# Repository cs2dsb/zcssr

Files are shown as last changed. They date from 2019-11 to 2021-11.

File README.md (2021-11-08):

# ZCSSR - Zero crossing solid state relay controller

A PCB and software for a SSR controller that monitors mains AC zero crossings to determine when to turn the SSR on.

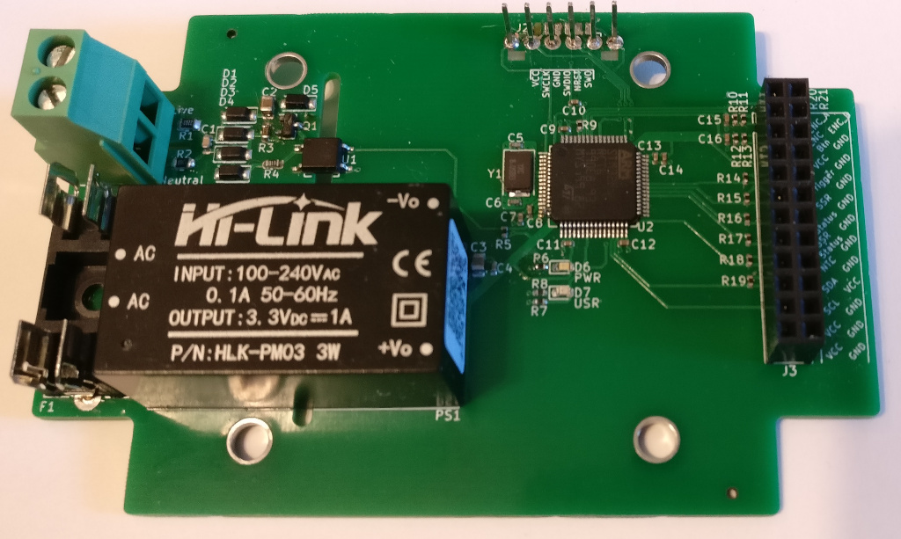
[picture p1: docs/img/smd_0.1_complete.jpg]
Image of v0.1 fully assembled

[more images](docs/img)

## Why

I wanted to build a spot welder from an old MOT (microwave oven transformer) but wasn't satisfied with simply enabling the SSR at random because this makes the pulse +/- 1 half mains cycle (10ms on 50Hz, 8.3ms on 60Hz). It probably doesn't make much difference in the grand scheme of things but I wanted to know exactly how long the pulses were. 

This controller solves that issue by monitoring the mains zero crossing and triggering the SSR just before a zero crossing - the SSR has it's own zero crossing circuit to actually turn on it's output so as long as the controller doesn't fire more than 1 cycle early it will work as expected.

I also wanted to completely finish an embedded project written in rust and this project seemed about the right size undertaking.

## Uses

* Spot welder
* Reflow oven
* Sous vide
* Smoker
* Probably other things that need temp input (K-Type thermocouple) and switched mains ouput

## Features

* Zero crossing detection circuit
  * Pulse at least 0.4ms before the zero crossing
  * Isolated
  * 100-240V, 50/60Hz
  * [Details](docs/SimpleIsolatedZeroCrossDetector.pdf)
* UI
  * Quadrature encoder with push button 
  * LED for general status
  * LED for SSR status
  * 4 digit 14-segment LCD display. I2C
  * Trigger input 
* Temperature monitoring
  * NTC thermister for monitoring SSR/Transformer temperature
  * K-Type thermocouple input. MAX31855
* STM32F1 64-pin LQFP MCU. Specifically STM32F103RCT but any should work
* SWD (serial wire debug) programming & debugging
* USB hardware. In theory USB programming will be possible but not yet implemented

## Tools used

Not a complete list. Will add to it as features get implemented

* [Kicad](http://www.kicad.org/)
* [Rust](http://www.rust-lang.org/)
  * [cortex-m](http://github.com/rust-embedded/cortex-m) and [cortex-m-rt](http://github.com/rust-embedded/cortex-m-rt)
  * [cortex-m-rtfm RTOS](http://github.com/rtfm-rs/cortex-m-rtfm)
  * [stm32-rs peripheral register definitions](http://github.com/stm32-rs/stm32-rs)
  * [stm32f1xx-hal HAL implementation](http://github.com/stm32-rs/stm32f1xx-hal)
  * [adafruit-alphanum4.rs driver for Adafruit 14-segment LED Alphanumeric Backpack](http://github.com/cs2dsb/adafruit-alphanum4.rs)
    * [ht16k33 LED driver](http://github.com/jasonpeacock/ht16k33)

## Documentation

### Getting started

* Clone the repo
* Run `./bootstrap` script which will:
  * Initialize git submodules
  * Run `firmware/bootstrap` which will:
    * Checks if OS dependencies are installed
      * Currently `gcc`, `gdb`, `openocd` and `libudev-dev`
      * `sudo firmware/install_apt_deps` will install these deps if you are using a distribution that uses `apt`
    * Install or update rustup
    * Install required rust embedded toolchains
    * Install utils from crates.io
      * cargo-binutils
      * cargo-watch
      * llvm-tools-preview
      * serialitm
    * Run a cargo check, build and doc of the firmware (will take quite a while the first time)
* Direct flashing the the device
  * `firmware/deploy_standalone` will start openocd, flash the program and restart the device
* Debugging with gdb
  * `firmware/run_openocd` in one terminal
  * `firmware/release` or `firmware/debug` to build and launch gdb
  * Take a look at `firmware/openocd.gdb` and the scripts above to tweak the behaviour
* Log output
  * Firmware built with `--feature itm` will log over SWD
  * `firmware/monitor_itm` will launch `serialitm` to print this output with the ITM control characters stripped out. You may need to tweak the script if your uart dongle isn't `/dev/ttyUSB0`
* Tmux
  * `firmware/tmux_workspace` is a script that will open a tmux session with `firmware/run_openocd`, `firmware/monitor_itm` and `firmware/watch` in differnt panes to make development easy. Just type `./release` in one of the spare panes to deploy the software with gdb

### ITM logging

The code uses ITM logging to indicate start up progress and log info like temperatures and user config. If the ITM feature is enabled, the microcontroller won't run without openocd connected because there is some debug config openocd does to the chip that makes ITM work. I've added the obvious checks to the [itm_logger](https://github.com/cs2dsb/itm_logger.rs) crate but there's still something missing that I haven't got to the bottom of yet. There's [an issue](https://github.com/cs2dsb/itm_logger.rs/issues/1) to track it. The bottom line is if you want to be able to plug the hardware into the mains without OpenOCD connected you need to disable the `itm` feature (`firmware/deploy_standalone` already does this.)

### More info

Check [the docs folder](docs) for information on setting up the dev environment and various info on making the hardware.

## Mains warning

* Mains is dangerous, see the disclaimer
* A specific issue you might hit is powering the device over USB during development then plugging the mains in while the USB dongle is still attached. The mains will power the AC/DC on the board and that will backfeed 5v into the 3.3v/5v provided by the dongle. It's fine to leave the dongle connected if you disconnect it's 3.3v/5v line - only ground, swd, swclk should be connected to the ST-LINK if you want to plug the mains in. The UART connected to ground and swo is also fine. If you do backfeed 5v to the ST-LINK expect the ST-LINK to break as a minimum and the USB port it's connected to as a worst case. 

## Disclaimer

* This project uses mains electricity and will kill you if you handle it improperly
* You are responsible for your own safety
* Despite best efforts the author makes no guarantees that this design is safe, fit for purpose or meets any quality standards
* If you decide to build this or a similar device you must understand and take necessary safety precautions before proceeding
* The author cannot be held responsible for any damages or any form of loss that comes as a result of using any information found in this project

## License

This template is licensed under either of

- Apache License, Version 2.0 ([LICENSE-APACHE](LICENSE-APACHE) or
  http://www.apache.org/licenses/LICENSE-2.0)

- MIT license ([LICENSE-MIT](LICENSE-MIT) or http://opensource.org/licenses/MIT)

at your option.

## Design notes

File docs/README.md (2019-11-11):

# Docs

## Technical

[Setting up the dev environment](setting_up_dev_env.md)

[Generating gerbers and fab outputs](generating_gerbers_and_fab_outputs.md)

[Placing an order for assembled boards with JLCPCB](placing_jlcpcb_order.md)

## Flavour

[Project log](project_log.md)

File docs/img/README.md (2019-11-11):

# TH_v0.1

* ATMEGA328P based

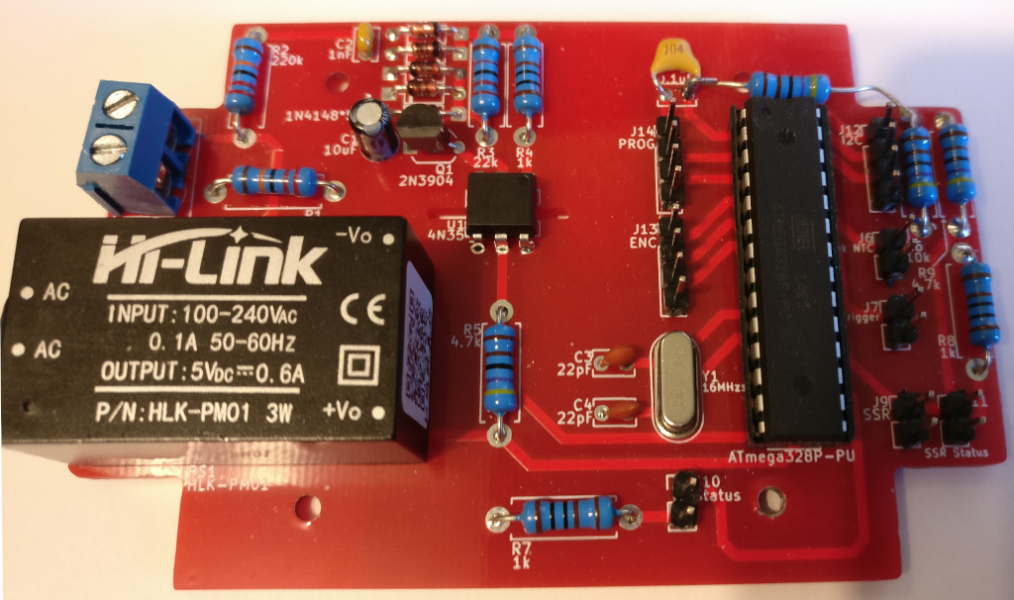
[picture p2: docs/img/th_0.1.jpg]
Image of TH v0.1 fully assembled


# SMD_v0.1

* STM32F1 based 

### Board as it came from JLCPCB assembly service

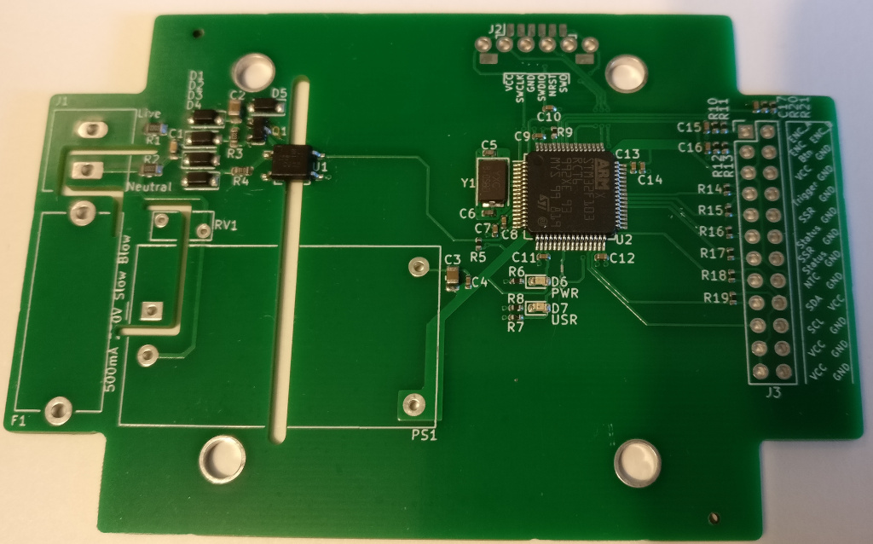
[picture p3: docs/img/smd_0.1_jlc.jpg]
Image of v0.1 from jlc


### Fully assembled with through hole components

Image of v0.1 fully assembled

# SMD_v0.2

* Added MAX31855
* Added USB 
* Moved connectors closer to edges to free up space in the middle of the enclosure

### Render from kicad
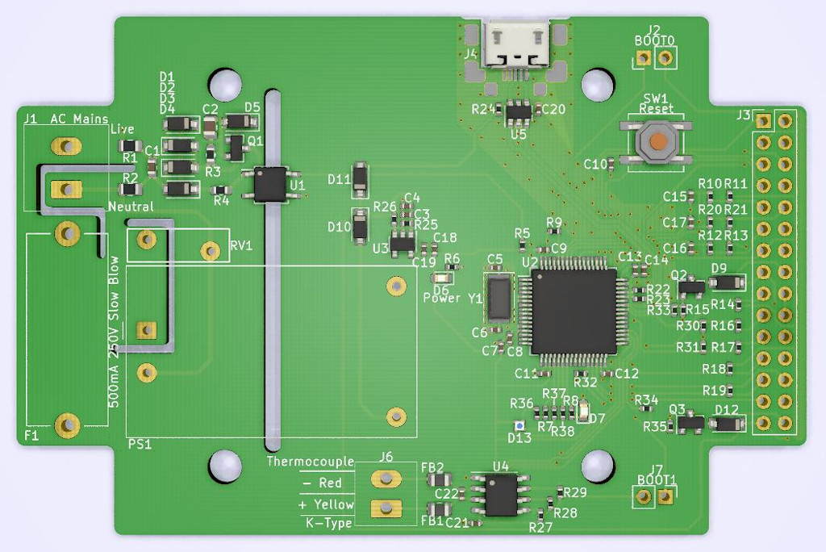
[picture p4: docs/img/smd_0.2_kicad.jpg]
Image of v0.2 kicad render


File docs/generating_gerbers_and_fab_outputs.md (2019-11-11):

# Generating gerbers and fab outputs

## Bill of materials
1. Open the schematic 
2. Click the BOM button: BOM button
3. Select `bom2grouped_csv`
4. Press `Generate`
5. Navigate to the project folder in the terminal
6. Move "zero_crossing_detector" (note no extension) to "print/zero_crossing_detector-bom.csv"
    * `mv zero_crossing_detector print/zero_crossing_detector-bom.csv`
7. Close the schematic

## Gerbers
1. Open the kicad_pcb
2. Press `b` to refill zones
3. Click the Plot button: Plot button
4. Check the options are correct
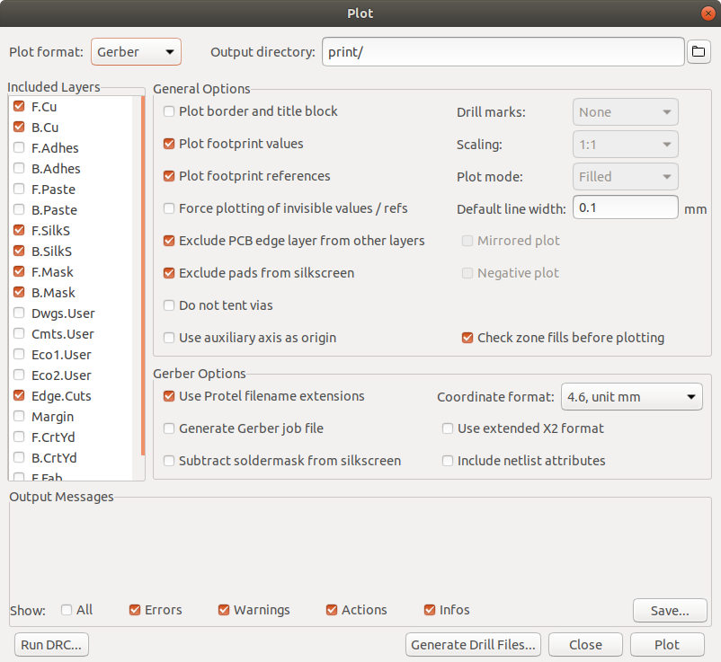
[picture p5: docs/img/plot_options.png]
Plot options
    
5. Press `Plot`
6. Press `Generate Drill Files...`
7. Check the drill options are correct
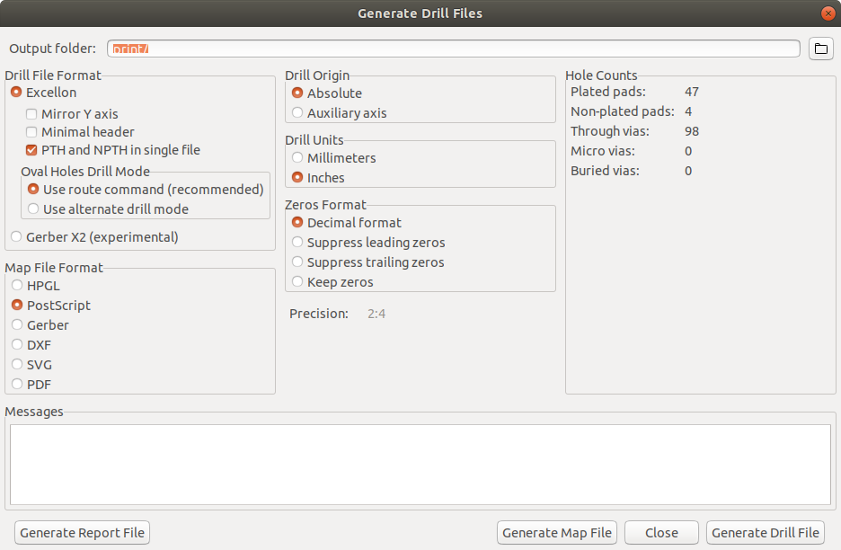
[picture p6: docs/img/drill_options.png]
Drill options
    
8. Press `Generate Drill File`
9. Close the drill window
10. Close the plot window

## Footprint position file
1. Still in kicad_pcb
2. Click File | Fabrication Outputs | Footprint Position (.pos) File...
3. Check the pos options are correct
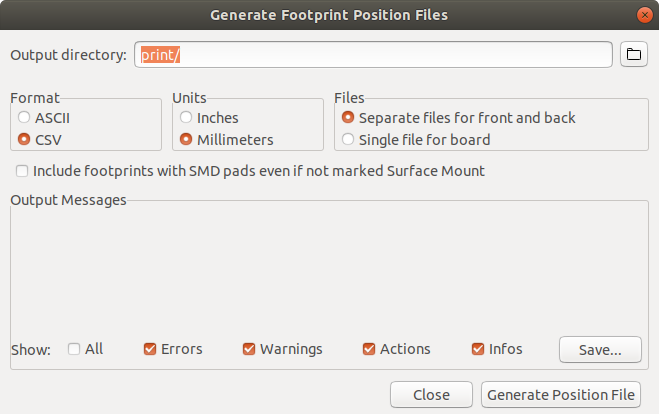
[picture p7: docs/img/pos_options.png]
Footprint pos options
    
4. Press `Generate Position File`

## Post processing the files
1. Go to the project folder in the terminal
2. Go to the print folder
3. Run `rename_gbrs.sh` which will
    * Delete any old `print.zip`
    * Rename the `PosX` and `PosY` columns in the footprint pos file to `Mid X` and `Mid Y` as required by JLCPCB
    * Make sure the BOM is csv rather than semi-colon separated (probably no longer necessary)
    * Rotate `Q1` to fix alignment on reel
    * Zip everything up in `print.zip`

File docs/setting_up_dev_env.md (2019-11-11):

# Setting up the dev environment

This project has been developed on a Linux development environment. The scripts and steps discussed below are unlikely to work on Windows or OSX. [The Embedded Rust Book](https://rust-embedded.github.io/book/) introduction section has a detailed installation guide for all platforms. You will also need to adjust `firmware/.cargo/config` which discussed [in the hardware section of the book](https://rust-embedded.github.io/book/start/hardware.html). The [cortex-m-quickstart repo](https://github.com/rust-embedded/cortex-m-quickstart) also has lots of useful information. If you follow that then skip to the [Project specific section](#project-specific) you should be all set up.

## Tools
### openocd
* Install [openocd](http://openocd.org/getting-openocd/)
* `apt install openocd` will likely be sufficient if you are using Ubuntu or Debian
* If you have any issues (particularly around the device not being reset correctly) consider installing a more up to date version from source

### rustup
* Install [rustup](https://rustup.rs/)

### bootstrap `(firmware/bootsrap)`
This script will 
* add the required toolchains using `rustup`
* add `cargo-binutils`
* add `llvm-tools-preview`
* add `cargo-watch`
* kick off a full build & doc 

## Project specific
### run_openocd `(firmware/run_openocd)`
This script will 
* launch `openocd` with the included `openocd.cfg` configuration

You'll need to have this running for [release](#release-firmwarerelease), [debug](#debug-firmwaredebug), [device_reset_halt](#device_reset_halt-firmwaredevice_reset_halt) and [device_reset_run](#device_reset_run-firmwaredevice_reset_run) to work correctly.

### watch `(firmware/watch)`
This script will
* monitor the rust source and build whenever a file changes

### release `(firmware/release)`
This script will
* run `device_reset_halt` to ask openocd to reset and halt the target hardware
* run the release version of the `main` binary (`src/bin/main.rs`) on the target hardware using `gdb`

### debug `(firmware/debug)`
As [release](#release-firmwarerelease) but in compiled in release mode which makes stepping through code easier but can be extremely slow in some circumstances. Suggest adding `cortex_m::asm::bkpt()` just before whatever you want to step through then running `debug`.

### device_reset_halt `(firmware/device_reset_halt)`
This script will
* telnet to openocd (127.0.0.1:4444) and issue a `reset halt` command which will cause the MCU to reset and stop ready to be programmed

### device_reset_run `(firmware/device_reset_run)`
This script will
* telnet to openocd (127.0.0.1:4444) and issue a `reset run` command which will cause the MCU to reset and run whatever is currently on it's Flash/SRAM (depending on BOOT0/1 jumper config)

### tmux_workspace `(firmware/tmux_workspace)`
This script will
* start or resume a `tmux` session
* split the window into 5
* run `watch`
* run `../../itm_log` //TODO: upload this tool
* run `openocd`

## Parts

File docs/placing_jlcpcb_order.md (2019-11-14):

# Placing an order for assembled boards with JLCPCB

Make sure you've run through [Generating gerbers and fab outputs](generating_gerbers_and_fab_outputs.md) first.

1. Head over to [JLCPCB](https://jlcpcb.com/quote) and log in/register
2. Press `Add your gerber file`
    
    Add gerber button
3. Upload `print/print.zip` 
4. Check the options to make sure they are compatible with SMT assembly:
    * Layers: 2
    * PCB Thickness: 1.6
    * PCB Color: Green
    * Copper Weight: 1oz
    * Panel By JLCPCB: No
    * Gold Fingers: No
    * Castellated Holes: No
    * Different Design: No
    * **Specify Order Number: Yes**
5. Enable `Assemble your PCB boards`

    Assemble your PCB boards
6. Select the top side for assembly
7. Press `Confirm`
8. Press `Add BOM file`
    
    Add bom file
9. Upload `print/zero_crossing_detector-bom.csv`
10. Press `Add CPL file`
    
    Add cpl file
11. Upload `print/zero_crossing_detector-top-pos.csv`
12. Press `Next`
13. Check and confirm every part against the BOM
    * It's pretty good at matching most but occasionally you'll have to pick manually
    * There are currently no connectors in the parts database so the USB and other connectors will have to be ordered separately and manually installed
14. Press `Next`
15. Check the Pin 1 markers (red dots) in the `Review Parts Placement` preview
16. Press `Save to cart`
17. Checkout

## LCSC Parts
There are some parts that JLCPCB can't assemble which can be ordered on LCSC.

If you registered with LCSC before 12-Mar-2019 you can get a discount/free shipping on LCSC parts when you have a JCPCB order waiting production. [See for details](https://support.lcsc.com/article/24-do-you-offer-combine-shipment-with-pcbs)

These parts need to be ordered (check BOM in case this list gets missed from an update):
* C52028 - MAX31855
* C89120 - Phoenix Contact 1711725 (Mains input)
* C89122 - Phoenix Contact 1751248 (Thermocouple input)
* C206887 - Littlefuse fuse holder
* C187509 - Littlefuse fuse cover
* C56496 - Header pins
* C136145 - NTC thermistor
* C140500 - 500mA slow blow fuse
* C209903 - 5V AC-DC power module
* C233184 - Varistor
* C361165 - ALPS rotary encoder (This one is detentless and doesn't have a threaded mounting column. There are a dozen different styles if you search for ALPS "coded rotary switches". Most of EC11 range is suitable but check for "With" in "Push-on switch" column in datasheet. EC12D have push buttons and are all suitable but are only available with detents and in relatively low pulse/rev)

## Other Parts
* [Enclosure](https://www.banggood.com/100x68x50mm-IP65-Waterproof-Electronic-Project-Enclosure-Case-DIY-Enclosure-Instrument-Case-p-1260023.html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) - the pcb is designed to fit in this box and there's **probably** enough space to fit the display, rotary encoder, LEDs and maybe even the SSR inside too. Check the [docs folder](..) for assembly details once the next version of the hardware has been tested
* [Display](https://www.banggood.com/5pcs-4-bit-Pozidriv-0_54-Inch-14-segment-LED-Digital-Tube-Module-Green-I2C-Control-2-line-Control-LED-Display-Screen-Module-p-1565722.html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) - the firmware expects this display but you could modify it to accept any I2C display
* [STLink](https://www.banggood.com/3pcs-3_35V-XTW-ST-LINK-V2-STM8STM32-Simulator-Programmer-Downloader-Debugger-With-20cm-Dupont-Wire-p-1183115.html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) - for programming the board. Listing is for 3; it's probably a good idea to get spares in case you blow one up (I did)
* SSR - I bought several `Crouzet 25A` and tore one down to make sure it was genuine. The Fotek SSR-25 relays are common and widely used but they are also almost all clones of varying quality. Some clones have 16A triacs inside which would still be perfectly sufficient but others have 4-8A triacs which is probably a fire waiting to happen if you're building a welder. You can get Crydom and other genuine SSRs on farnell/mouser/digikey/etc but expect to pay 5x as much as the clones. **If you do go with an SSR of unknown quality never leave it plugged in to the mains unattended and be prepared in case of fire**. Regardless of which SSR you go for make sure the NTC thermistor is connected to it's heatsink during operation. Some videos about clone SSRs and failures: [melted down](https://youtu.be/FV9t1GFVbhU), [clone teardown](https://youtu.be/DxEhxjvifyY).

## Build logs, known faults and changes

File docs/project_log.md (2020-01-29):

# Project log

## 5-Sept-2019

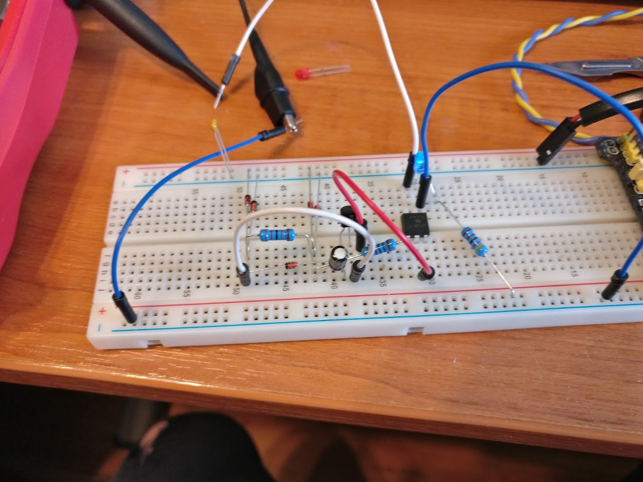
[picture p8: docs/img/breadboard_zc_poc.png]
breadboard poc
* Breadboard prototyped zero crossing circuit based on [this circuit](SimpleIsolatedZeroCrossDetector.pdf) (originally from drextel.net but the domain has sadly gone dormant). 
* There are simpler ZC circuits but this one appears to have some additional benefits, works really well and doesn't add much to the BOM cost
* Arduino POC code using hardware timer to detect ZC edges and ISR to record the timer count
    * Works ok, measures the width and time of the pulse with good precision
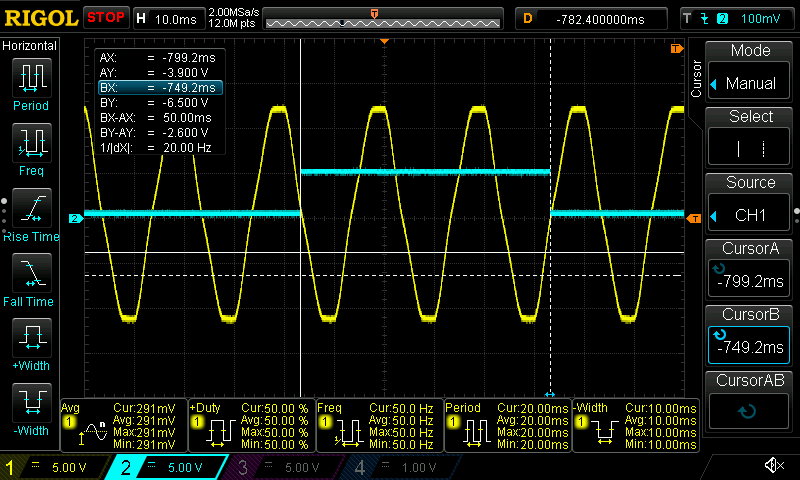
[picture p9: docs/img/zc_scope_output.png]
gpio output against AC
    * GPIO output on scope looks good against AC waveform 

## 6-Sept-2019

* Received Couzet SSRs
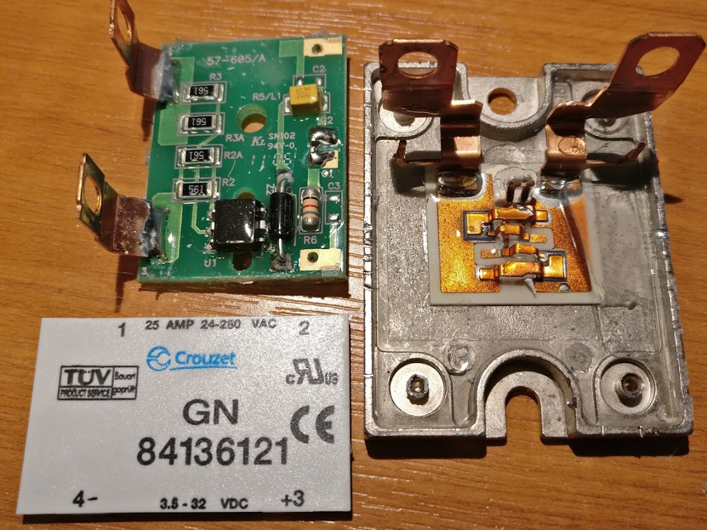
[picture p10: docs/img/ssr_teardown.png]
ssr teardown
* Tore one down to make sure they are genuine 
* Hooked up SSR output to scope and showed that triggering GPIO in ISR was sufficiently before the ZC to correctly enable the SSR in time for the ZC

## 8-Sept-2019

* Ordered TH_v0.1 boards from JLCPCB

## 25-Sept-2019

* Received TH_v0.1 boards Image of TH v0.1 fully assembled
* Missing pullup on RST. Working as expected other than that
* 14-Segment Adafruit display working nicely over I2C
* Rotary encoder seems like a reasonable input device for the kind of config this needs (pulse1, delay1, pulse2, delay2)
* NTC working

## 7-Oct-2019

* Ordered SMD_v0.1 boards assembled from JLCPCB
* STM32F1 available for assembly as a basic part
* STM32 has richer set of peripherals than ATMEGA328P
    * Timer can do quadrature encoder input with no software interaction
    * Timer can do PWM input capture to measure the frequency and duty of the ZC signal
    * Timer can be configured in one-shot mode to enable the SSR for a given time and have the hardware turn it off regardless of a crashed program or delayed ISR or something
* STM32 can also be programmed with rust and the F1 has pretty good support

## 22-Oct-2019

* Received SMD_v0.1 boards from JLCPCB Image of v0.1 from jlc
* Identified issues:
    * Q1 Base and Collector are switched. Resolved with some solder bodging
    * Varistor/Mov leads are too thick for holes. Resolved with some solder bodging
    * Pwr led is annoyingly bright with 150Ω resistor. Had a 680Ω to replace it with but still too bright. Changed to 1k in schematic
    * ZC input on TIM2_CH3 can't be used for PWM input. Fortunately CH1 & CH2 are adjacent so resolved with some solder bodging

## 28-Oct-2019

* Note to self: don't plug the mains in when loose dupont wires are nearby. Destroyed ST-Link and F1 on POC board
* Ordered fuse cover to partially protect mains contacts
* Added longish ribbon with all low voltage outputs and fitted lid of box so nothing can get in by accident

## 3-Nov-2019

* Recieved replacement ST-Link
* Basically all the bits are implemented in rust. Few PRs for stm32f1xx-hal to enable extra timers
* Implemented driver for 14-segment display [adafruit-alphanum4.rs](https://github.com/cs2dsb/adafruit-alphanum4.rs)
    * Added to rust-embedded awesome list which is nice. Hopefully it'll be useful to someone

## 11-Nov-2019

* Did quite a bit of documentation for the repo
* Finished updating SMD_v0.2 PCB ready to order
    * Added MAX31855K K-Type thermocouple interface IC to enable reflow oven use case
    * Added USB port, mainly as an experiment to see if I can get it working and useful (USB DFU mode would be amazing but failing that, something similar to the TS-100 USB functionality would be ok)
    * Added a physical reset button. In theory, SWD doesn't need hardware reset and openocd should be able to connect to the core with just CLK, DIO and GND but in practice I've had boards fairly regularly get into a state where it can't connect reliably. Resetting by shorting NRST to GND resolves this and the board will work without reset until the ST-Link is unplugged or the boards power is cycled. I haven't been able to get to the bottom of it - the core is running, the gpio for SWD hasn't been reconfigured and I've tried every permutation of reset_config in openocd. There's some speculation on some forums that the ST-Link firmware is to blame as it's not a proper JTAG adapter and merely emulates some features; I could buy a proper JTAG adapter to rule this out but I want these boards to be programmable by anyone with a cheap adapter. This programming faff partially fed into the desire to add USB and explore USB bootloading. 

## 13-Nov-2019

* Changed AC-DC module from 3.3V to 5V to allow 5V SSR (or relay) output
* Switched LDO to AP2112 as used on several Adafruit boards. It has better specs and doesn't require tantilum caps to be stable
* 5V in allows using simple diodes to block backfeeding AC-DC or USB 5V inputs
* Added transistors to control SSR and MISC outputs so they can be 5V rather than directly driven from MCU GPIO pins

## 15-Nov-2019

* Added tiny 1x1mm rgb LED to spare pins near the existing LED. Mainly want to see how bright this tiny LED is at ~5ma

## 16-Nov-2019

* Placed an order for the next version of the PCB

## 29-Nov-2019

* v0.2 PCBs arrived
* Updated the board pin hardware definitions
* Tested all the previously implemented features
    * It all still works
* RGB led added in this version is oriented incorrectly
* Haven't tested USB

## 9-Jan-2020

* Finished implementing [MAX31855](https://github.com/cs2dsb/max31855.rs) and testing thermocouple

## 14-Jan-2020

* Tested RTFM 5: issue I was previously seeing with hardware interrupts not getting called appears to be resolved
* Converted spot_welder to use RTFM 5 and some general housekeeping

## 19-Jan-2020

* Fitted the new hardware into the case and hooked up a transformer to test the ZC and mains side of things
* All working as expected - probably shouldn't be surprising but after taking a 2 month break I automatically assume all the hardware and code was rubbish and wouldn't work.

## 25-Jan-2020

* Brought all the tested bits a pieces together into basically finished spot welder
    * UI settings are snapshotted when the weld is triggered
    * Oscilloscope shows pulse lengths match configured values
* Refactored the UI out into zcssr lib
    * I originally thought it might be a useful reusable thing but actually a 4 digit display controlled with a rotary encoder is probably too specific to be much use elsewhere. Maybe it can be extracted later; some of the code like scrolling text might be useful...
    * As part of the refactoring I converted the display strings into GenericArray<AsciiChar, typenum::Uxx> and got rid of the current text buffer. This means there's no copying the strings when changing screens and each string is only as long as necessary not some MAX_LENGTH constant. I haven't worked out the memory savings but it feels better to have a zero cost, no copying version.
    * Experimented with using trait objects/dynamic dispatch to make the Ui/Screen api nicer but found that dynamic dispatch introduced a measurable (oscilloscope on toggled IO pin) delay of several hundred cycles. Since I'm matching on the current screen anyway static dispatch isn't much more of a hassle but does prevent something clean like self.with_current_screen(|screen| screen.do_the_thing()). To reduce duplicated match (self.current_screen) blocks I made a macro to plop the match around a closure - it basically mimics the api I would have done with trait objects except the closures are manually monomorphised by the macro.
* Trigger cable is picking up noise and causing the interrupt to run erroneously
    * Added hardware debouncing to the trigger input
    * Since a false interrupt on the trigger could cause a weld at an inopportune time I'll have to revisit it once the HW debouncing is in to see if I need to add a software solution on top - requiring a press longer than a given time and not occuring again within a given time would be fairly easy to implement and could provide more safety.
* Related to trigger noise, I'm also seeing erroneous data on the UART dongle I'm using when big mains devices turn on/off in the same room (electic heater, lights, printer). This happens when the mains plug for the ZCSSR isn't connected and everything is powered over USB so I don't really know what the exact cause is - the UART dongle has a high quality shielded cable, maybe it's noise being conducted to the USB ground? Who knows...

## 26-Jan-2020

* Moved majority of the hardware configuration out of spot_welder (the bin) into the crate board.rs
    * This should mean that creating new bins for reflow_oven, sous_vide, etc. will reuse most of this code and be fairly trivial - just the control algorithms for those specifc devices
    * The pattern I went for is the board has a trait `Configure` which it implements for the type aliases it defines for the hardware. The consumer then does `LedStatus::configure((gpiox.px1, etc))` to get a configured `LedStatus` back. The pattern of having an associated type on the trait that specifies the requred parameters was nicked from amethyst.rs's system trait. I'm not sure if this gives any benefit over a simple function configure_led_status(...)

## 27-Jan-2020

* Took the I2C hung fix I hacked into local copy of the hal out and put it in a separate crate: [i2c_hung_fix](https://github.com/cs2dsb/i2c_hung_fix.rs) since it only needs embedded-hal InputPin and Output pin and should work for anything that implements those on the I2C pins
* Moved the UI string to GenericArray code into a proc_macro so that the length of the array is correctly enforced. It still uses unsafe union transmuting but both sides lengths are calculated in the proc macro instead of manually entered so it should be safe enough. Once core::mem::transmute becomes a const_fn this will be unnecessary [see #53605](https://github.com/rust-lang/rust/issues/53605)

## 29-Jan-2020

* Shifted the PCB around to put the AC/DC supply is right on one of the short edges of the board in the hope this will fit more comfortably next to an SSR inside the enclosure
* Removed the RGB led, I only added it on a whim to test how bright and small the LED was. It's not much use inside the enclosure and it adds to the SMD assembly cost
* Switched from using hacky d2xx ITM log utility to [serialitm](https://crates.io/crates/serialitm) from crates.io which does everything needed for this project
    * If I add typed ITM data output for the reflow oven/sous vide to log temperatures I may need some extra features but this util is sufficient for now
* Updated bootstrap scripts and readme

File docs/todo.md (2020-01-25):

# Todo

## Firmware

### Shared
- Test basic hardware
    - [x] Debug LED on PCB near MCU
    - [x] Status LED to indicate ready, error, etc.
    - [x] Status LED to indicate SSR status. Typically same state as SSR_EN
    - [x] SSR output
        - [x] One shot timer to trigger fixed length pulse under hardware control
    - [x] Misc output (fans etc)
    - [x] Rotary encoder
    - [x] NTC thermister
    - [x] Zero crossing detection circuit
    - [x] Trigger
    - [x] I2C display
    - [ ] USB
    - [x] Thermocouple

## Hardware
- [x] Add hardware debouncing to trigger
- [x] Add pull-up to SCL
- [x] Make I2C pull ups optional since adafruit module already includes them
- [x] Make I2C pull ups 2.2k since 3.3v not 5v

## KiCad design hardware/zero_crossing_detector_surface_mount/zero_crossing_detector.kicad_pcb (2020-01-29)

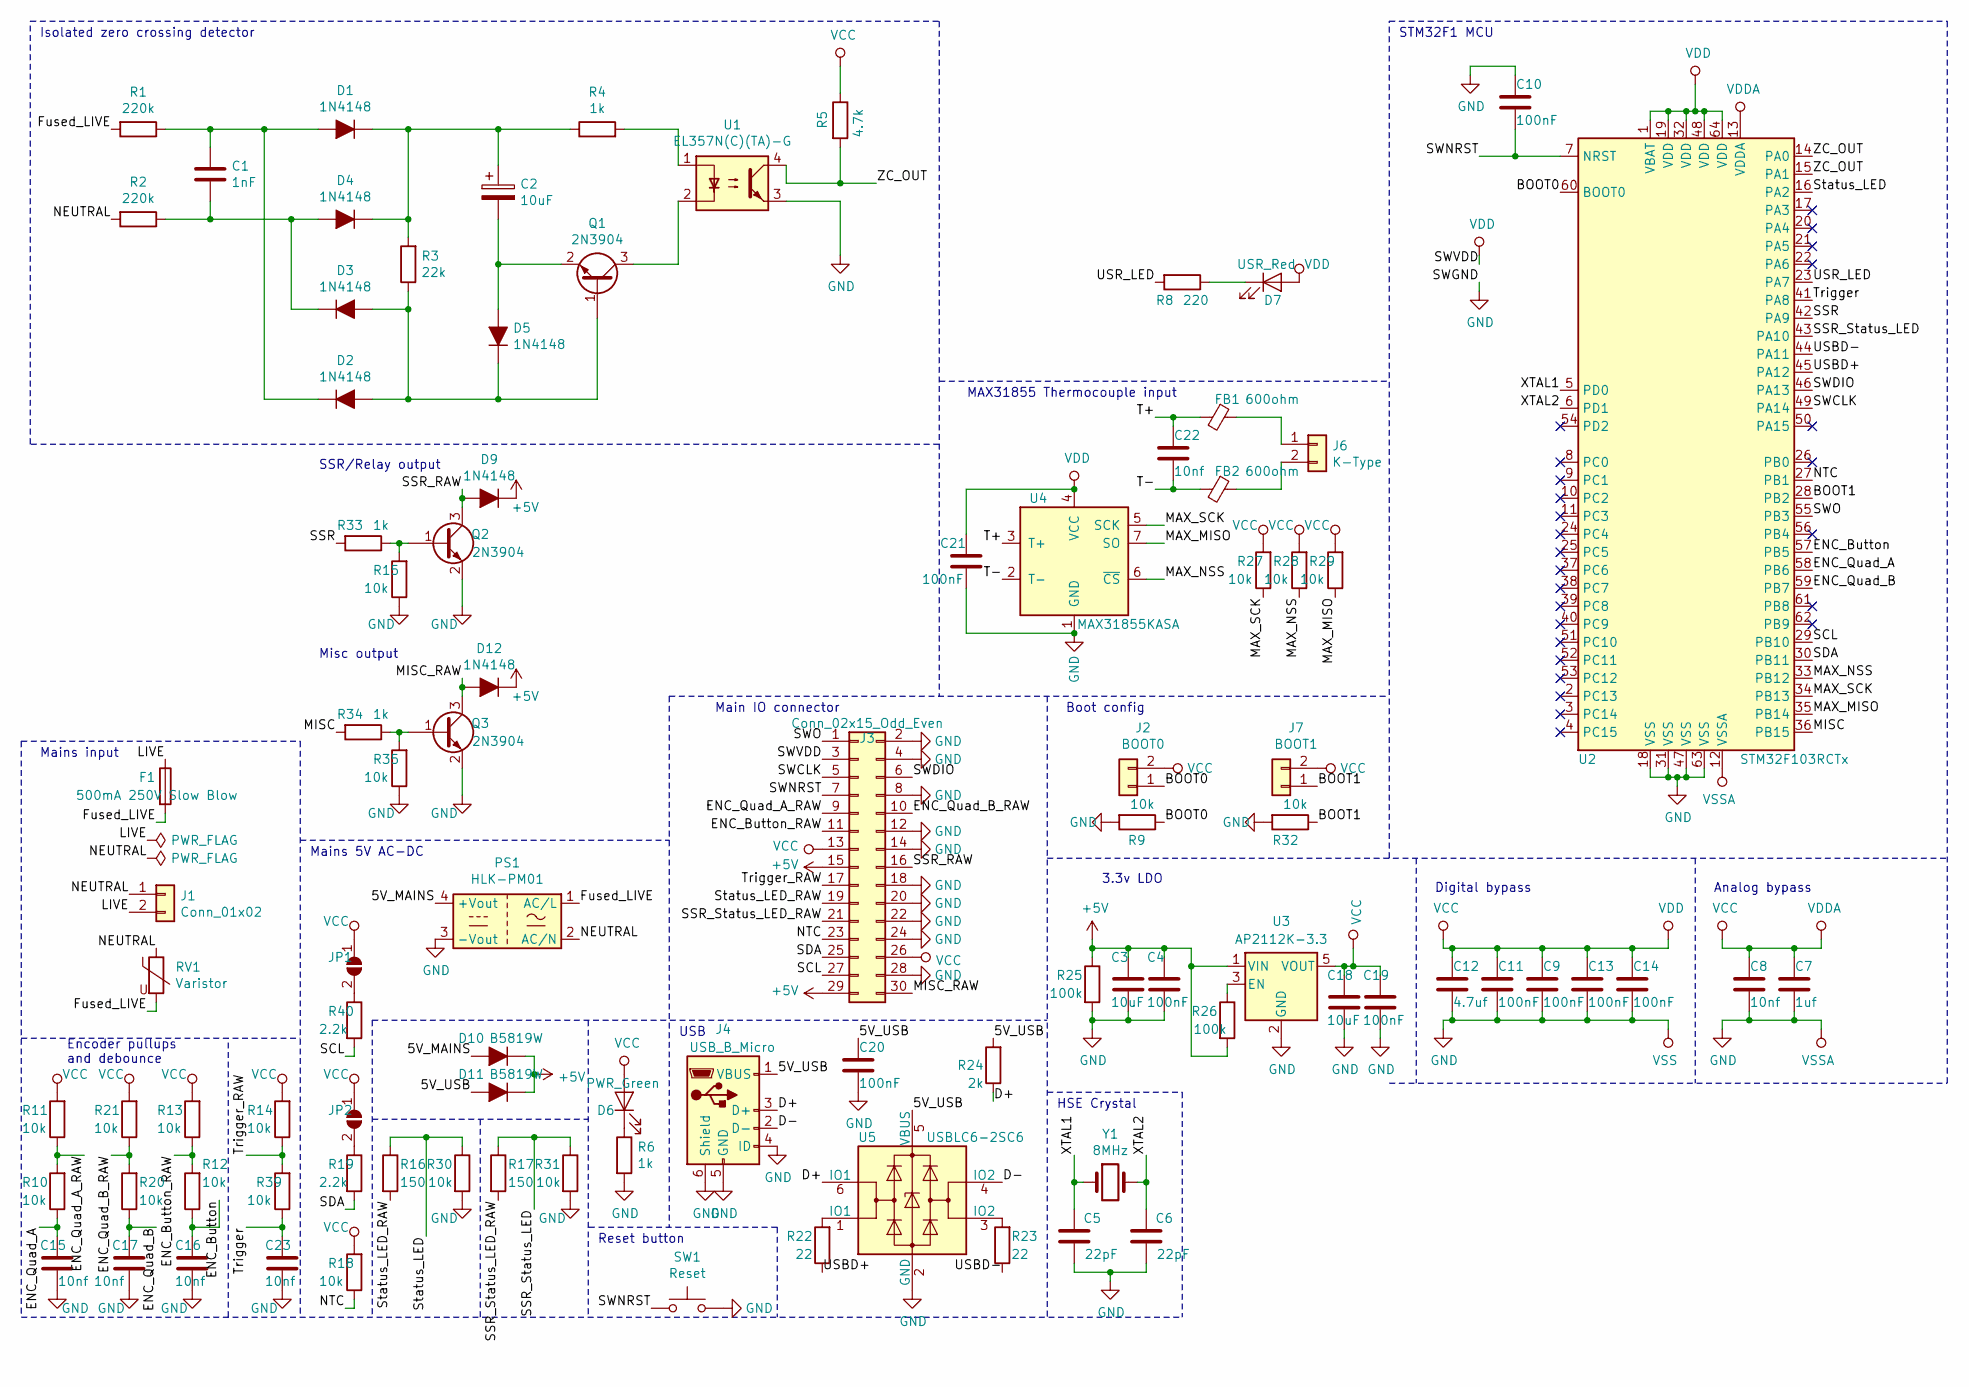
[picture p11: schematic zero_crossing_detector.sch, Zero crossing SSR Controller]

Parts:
C1: 1nF; C_0603_1608Metric; Part Number CL10B102KB8NNNC; LCSC Part Number C1588
C2: 10uF; C_0805_2012Metric; Part Number CL21A106KAYNNNE; LCSC Part Number C15850
C3, C18: 10uF; C_0402_1005Metric; Part Number CL05A106MQ5NUNC; LCSC Part Number C15525
C4, C9, C10, C11, C13, C14, C19, C20, C21: 100nF; C_0402_1005Metric; Part Number CL05B104KO5NNNC; LCSC Part Number C1525
C5, C6: 22pF; C_0402_1005Metric; Part Number 0402CG220J500NT; LCSC Part Number C1555
C7: 1uf; C_0402_1005Metric; Part Number CL05A105KA5NQNC; LCSC Part Number C52923
C8, C15, C16, C17, C22, C23: 10nf; C_0402_1005Metric; Part Number CL05B103KB5NNNC; LCSC Part Number C15195
C12: 4.7uf; C_0402_1005Metric; Part Number CL05A475MP5NRNC; LCSC Part Number C23733
D1, D2, D3, D4, D5, D9, D12: 1N4148; D_SOD-123; Part Number 1N4148W; LCSC Part Number C81598
D6: PWR_Green; LED_0603_1608Metric; Part Number 19-217/GHC-YR1S2/3T; LCSC Part Number C72043
D7: USR_Red; LED_0603_1608Metric; Part Number 红灯 0603; LCSC Part Number C2286
D10, D11: B5819W; D_SOD-123; Part Number B5819W; LCSC Part Number C8598
F1: 500mA 250V Slow Blow; Fuseholder_Cylinder-5x20mm_Stelvio-Kontek_PTF78_Horizontal_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; Part Number 64600001003,5T.0500240000R1D; LCSC Part Number C206887,C14050
FB1, FB2: 600ohm; L_0805_2012Metric; Part Number GZ2012D601TF; LCSC Part Number C1017
J1: Conn_01x02; Terminal_Block_Dinkle_EK508V_1x02_P5.08mm_Vertical; Part Number MKDS3/2-5.08; LCSC Part Number C89120
J2: BOOT0; PinHeader_1x02_P2.54mm_Vertical
J3: Conn_02x15_Odd_Even; PinHeader_2x15_P2.54mm_Vertical
J4: USB_B_Micro; ZX62M-B-5P(30)
J6: K-Type; PhoenixContact_MKDS_2-3.5; Part Number 1751248; LCSC Part Number C89122
J7: BOOT1; PinHeader_1x02_P2.54mm_Vertical
JP1, JP2: SolderJumper_2_Open; SolderJumper-2_P1.3mm_Open_TrianglePad1.0x1.5mm
PS1: HLK-PM01; Converter_ACDC_HiLink_HLK-PMxx; Part Number HLK-PM01; LCSC Part Number C209903
Q1, Q2, Q3: 2N3904; SOT-23; Part Number 2n3904S-RTK/P; LCSC Part Number C18536
R1, R2: 220k; R_0805_2012Metric; Part Number 0805W8F2203T5E; LCSC Part Number C17556
R3: 22k; R_0603_1608Metric; Part Number 0603WAF2202T5E; LCSC Part Number C31850
R4: 1k; R_0603_1608Metric; Part Number 0603WAF1001T5E; LCSC Part Number C21190
R5: 4.7k; R_0402_1005Metric; Part Number 0402WGF4701TCE; LCSC Part Number C25900
R6, R33, R34: 1k; R_0402_1005Metric; Part Number 0402WGF1001TCE; LCSC Part Number C11702
R8: 220; R_0402_1005Metric; Part Number 0402WGF2200TCE; LCSC Part Number C25091
R9, R10, R11, R12, R13, R14, R15, R18, R20, R21, R27, R28, R29, R30, R31, R32, R35, R39: 10k; R_0402_1005Metric; Part Number 0402WGF1002TCE; LCSC Part Number C25744
R16, R17: 150; R_0402_1005Metric; Part Number 0402WGF1500TCE; LCSC Part Number C25082
R19, R40: 2.2k; R_0402_1005Metric; Part Number 0402WGF2201TCE; LCSC Part Number C25879
R22, R23: 22; R_0402_1005Metric; Part Number 0402WGF220JTCE; LCSC Part Number C25092
R24: 2k; R_0402_1005Metric; Part Number 0402WGF2001TCE; LCSC Part Number C4109
R25, R26: 100k; R_0402_1005Metric; Part Number 0402WGF1003TCE; LCSC Part Number C25741
RV1: Varistor; RV_Disc_D12mm_W3.9mm_P7.5mm; Part Number 10D391K; LCSC Part Number C233184
SW1: Reset; SW_SPST_B3SL-1002P; Part Number TS-1187A-B-A-B; LCSC Part Number C318884
U1: EL357N(C)(TA)-G; SOP-4_3.8x4.1mm_P2.54mm; Part Number EL357N(C)(TA)-G; LCSC Part Number C29981
U2: STM32F103RCTx; LQFP-64_10x10mm_P0.5mm; Part Number STM32F103RCT6; LCSC Part Number C8323
U3: AP2112K-3.3; SOT-23-5; Part Number AP2112K-3.3TRG1; LCSC Part Number C51118
U4: MAX31855KASA; SOIC-8_3.9x4.9mm_P1.27mm
U5: USBLC6-2SC6; SOT-23-6; Part Number USBLC6-2SC6; LCSC Part Number C7519
Y1: 8MHz; Crystal_SMD_5032-2Pin_5.0x3.2mm; Part Number X50328MSB2GI; LCSC Part Number C115962

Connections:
+5V: C3.1, C4.1, D9.1 (K), D10.1 (K), D11.1 (K), D12.1 (K), J3.15, J3.29, R25.1, R26.2, U3.1 (VIN)
/5V_MAINS: D10.2 (A), PS1.4 (+Vout)
/5V_USB: C20.1, D11.2 (A), J4.1 (VBUS), R24.2, U5.5 (VBUS)
/BOOT0: J2.1, R9.1, U2.60 (BOOT0)
/BOOT1: J7.1, R32.1, U2.28 (PB2)
/D+: J4.3 (D+), R24.1, U5.6 (IO1)
/D-: J4.2 (D-), U5.4 (IO2)
/ENC_Button: C16.1, R12.1, U2.57 (PB5)
/ENC_Button_RAW: J3.11, R12.2, R13.1
/ENC_Quad_A: C15.1, R10.1, U2.58 (PB6)
/ENC_Quad_A_RAW: J3.9, R10.2, R11.1
/ENC_Quad_B: C17.1, R20.1, U2.59 (PB7)
/ENC_Quad_B_RAW: J3.10, R20.2, R21.1
/Fused_LIVE: F1.2, PS1.1 (AC/L), R1.2, RV1.2
/LIVE: F1.1, J1.2
/MAX_MISO: R29.1, U2.35 (PB14), U4.7 (SO)
/MAX_NSS: R28.1, U2.33 (PB12), U4.6 (~CS~)
/MAX_SCK: R27.1, U2.34 (PB13), U4.5 (SCK)
/MISC: R34.2, U2.36 (PB15)
/MISC_RAW: D12.2 (A), J3.30, Q3.3 (C)
/NEUTRAL: J1.1, PS1.2 (AC/N), R2.2, RV1.1
/NTC: J3.23, R18.1, U2.27 (PB1)
/SCL: J3.27, R40.2, U2.29 (PB10)
/SDA: J3.25, R19.2, U2.30 (PB11)
/SSR: R33.2, U2.42 (PA9)
/SSR_RAW: D9.2 (A), J3.16, Q2.3 (C)
/SSR_Status_LED: R17.1, R31.1, U2.43 (PA10)
/SSR_Status_LED_RAW: J3.21, R17.2
/SWCLK: J3.5, U2.49 (PA14)
/SWDIO: J3.6, U2.46 (PA13)
/SWNRST: C10.2, J3.7, SW1.1, U2.7 (NRST)
/SWO: J3.1, U2.55 (PB3)
/Status_LED: R16.1, R30.1, U2.16 (PA2)
/Status_LED_RAW: J3.19, R16.2
/T+: C22.1, FB1.2, U4.3 (T+)
/T-: C22.2, FB2.2, U4.2 (T-)
/Trigger: C23.1, R39.1, U2.41 (PA8)
/Trigger_RAW: J3.17, R14.1, R39.2
/USBD+: R22.1, U2.45 (PA12)
/USBD-: R23.1, U2.44 (PA11)
/USR_LED: R8.2, U2.23 (PA7)
/XTAL1: C5.2, U2.5 (PD0), Y1.1
/XTAL2: C6.2, U2.6 (PD1), Y1.2
/ZC_OUT: R5.2, U1.4, U2.14 (PA0), U2.15 (PA1)
GND: C3.2, C4.2, C5.1, C6.1, C7.2, C8.2, C9.2, C10.1, C11.2, C12.2, C13.2, C14.2, C15.2, C16.2, C17.2, C18.2, C19.2, C20.2, C21.2, C23.2, J3.2, J3.4, J3.8, J3.12, J3.14, J3.18, J3.20, J3.22, J3.24, J3.28, J4.4 (ID), J4.5 (GND), J4.6 (Shield), PS1.3 (-Vout), Q2.2 (E), Q3.2 (E), R6.2, R9.2, R15.1, R25.2, R30.2, R31.2, R32.2, R35.1, SW1.2, U1.3, U2.12 (VSSA), U2.18 (VSS), U2.31 (VSS), U2.47 (VSS), U2.63 (VSS), U3.2 (GND), U4.1 (GND), U5.2 (GND)
unnamed: C1.1, D1.2 (A), D2.1 (K), R1.1
unnamed: C1.2, D3.1 (K), D4.2 (A), R2.1
unnamed: C2.1, D1.1 (K), D4.1 (K), R3.2, R4.1
unnamed: C2.2, D5.2 (A), Q1.2 (E)
unnamed: D2.2 (A), D3.2 (A), D5.1 (K), Q1.1 (B), R3.1
unnamed: D6.1 (K), R6.1
unnamed: D7.1 (K), R8.1
unnamed: FB1.1, J6.1
unnamed: FB2.1, J6.2
unnamed: JP1.2 (B), R40.1
unnamed: JP2.2 (B), R19.1
unnamed: Q1.3 (C), U1.2
unnamed: Q2.1 (B), R15.2, R33.1
unnamed: Q3.1 (B), R34.1, R35.2
unnamed: R4.2, U1.1
unnamed: R22.2, U5.1 (IO1)
unnamed: R23.2, U5.3 (IO2)
unnamed: R26.1, U3.3 (EN)
VCC: C7.1, C8.1, C9.1, C11.1, C12.1, C13.1, C14.1, C18.1, C19.1, C21.1, D6.2 (A), D7.2 (A), J2.2, J3.3, J3.13, J3.26, J7.2, JP1.1 (A), JP2.1 (A), R5.1, R11.2, R13.2, R14.2, R18.2, R21.2, R27.2, R28.2, R29.2, U2.1 (VBAT), U2.13 (VDDA), U2.19 (VDD), U2.32 (VDD), U2.48 (VDD), U2.64 (VDD), U3.5 (VOUT), U4.4 (VCC)

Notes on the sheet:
Encoder pullups and debounce
Reset button
USB
HSE Crystal
STM32F1 MCU
Digital bypass
Analog bypass
3.3v LDO
Boot config
Main IO connector
Mains 5V AC-DC
Mains input
Isolated zero crossing detector
MAX31855 Thermocouple input
SSR/Relay output
Misc output

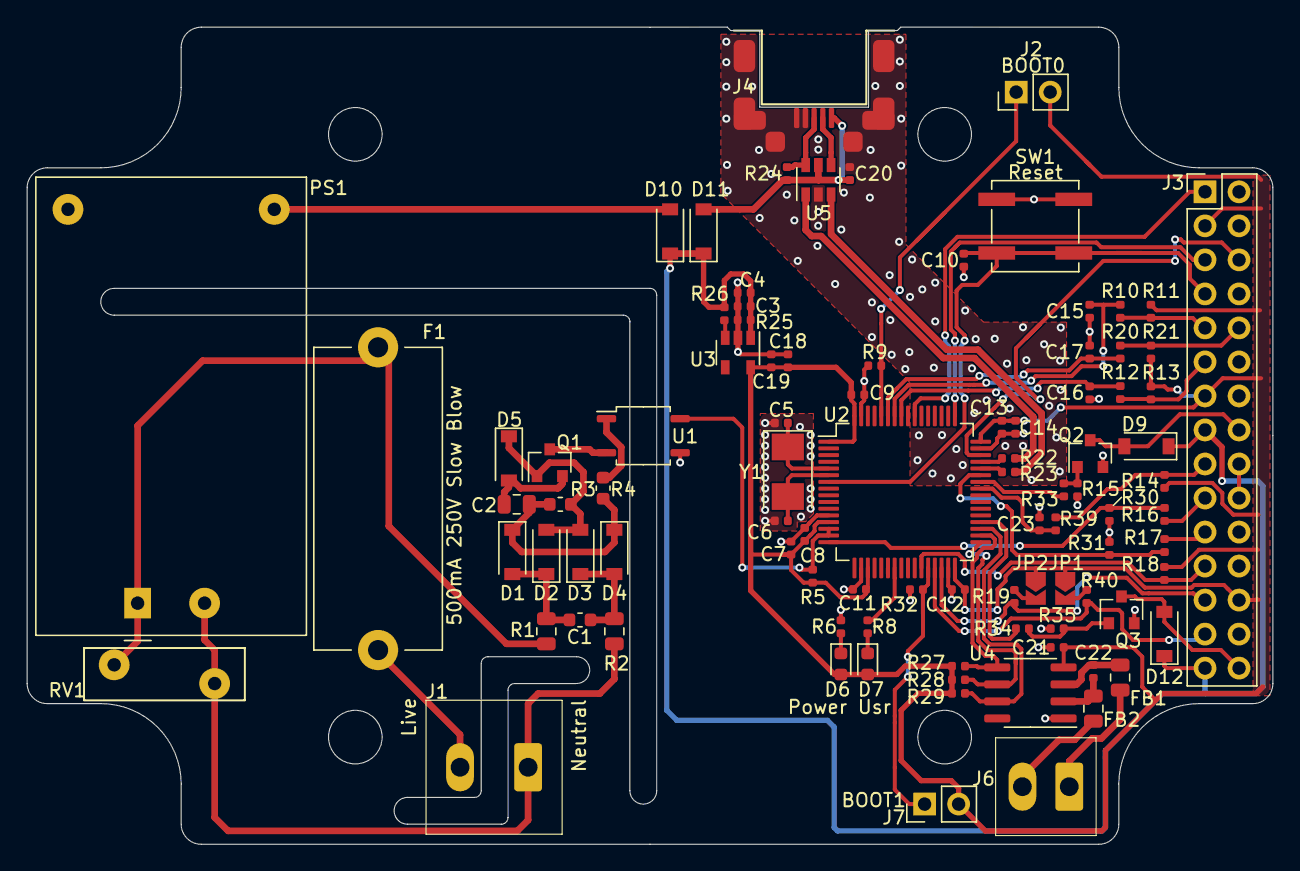
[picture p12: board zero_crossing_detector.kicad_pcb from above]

Board: 2 copper layers, 93.0 x 61.0 mm, 93 parts (0 on the bottom side), 64 nets.

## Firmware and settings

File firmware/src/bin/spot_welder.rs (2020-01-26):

#![no_std]
#![no_main]

#![feature(const_fn)]
#![cfg_attr(feature = "bench", feature(test))]

#[allow(unused_imports)]
use cortex_m::{asm, singleton};

use core::{
    panic::PanicInfo,
    sync::atomic::{self, Ordering},
};
use cortex_m::{
    interrupt,
    peripheral::Peripherals as CorePeripherals,
};

// For ln
use libm::F32Ext;

#[cfg(feature = "itm")] 
use cortex_m::{iprintln, peripheral::ITM};
    
use itm_logger::*;

use zcssr::{
    board::*,
    ui::welder::WelderUi,
};

#[cfg_attr(not(feature = "thermocouple"), allow(unused_imports))]
use max31855::{
    Max31855,
    Unit,
};

use stm32f1xx_hal::{
    prelude::*,
    rcc::Clocks,
    pac::{
        DMA1,
        Peripherals as DevicePeripherals,
    },
    gpio::{
        ExtiPin,
    },    
    adc::{
        Adc,
        AdcPayload,
        Continuous,
    },
    dma::{
        RxDma,
        CircBuffer,
        dma1::{
            C1 as DmaC1,
        },
    },
    delay::Delay,
};

#[cfg(not(feature = "dummy_zc"))]
use stm32f1xx_hal::{
    pwm_input::{
        ReadMode,
    },
};

#[derive(Clone, Copy, PartialEq)]
pub enum WeldState {
    Idle,
    AWeld,
    ADelay,
    BWeld,
    BDelay,
}

type NtcDmaBufferHandle = CircBuffer<[u16; 8], RxDma<AdcPayload<Ntc, Continuous>, DmaC1>>;

#[rtfm::app(device = stm32f1xx_hal::stm32, peripherals = true)]
const APP: () = {
    struct Resources {
        ui_timer: UiTimer,
        encoder: Encoder,
        zc_in: Zc,
        clocks: Clocks,
        ntc_dma_buffer: NtcDmaBufferHandle,
        display: Display,
        thermocouple: Thermocouple,
        activity_led: LedUsr,
        ssr_timer: Ssr,
        enc_button: EncBtn,
        trigger_button: Trigger,
        status_led: LedStatus,
        welder_ui: WelderUi,

        #[init(-400.)]
        last_ntc_temp: f32,

        #[init(-400.)]
        last_thermocouple_temp: f32,

        #[init(false)]
        weld_triggered: bool,
    }
    
    #[init]
    fn init(cx: init::Context) -> init::LateResources {
        configure(cx.device, cx.core).unwrap()
    }

    #[idle]
    fn idle(_cx: idle::Context) -> ! {
        loop {
            asm::wfi();
        }
    }

    /// EXTI9_5 Interrupt handles the quad encoder button and the trigger button
    #[task(binds = EXTI9_5, resources = [
        encoder, 
        welder_ui,
        last_ntc_temp,
        last_thermocouple_temp,
        weld_triggered,
        enc_button,
        trigger_button,
        display,
    ])]
    fn exti9_5(cx: exti9_5::Context) {        
        if cx.resources.enc_button.check_interrupt() {
            cx.resources.enc_button.clear_interrupt_pending_bit();
            debug!("EXTI encoder button pressed");
            encoder_button_pressed(cx.resources.welder_ui, cx.resources.encoder, cx.resources.display);
        } 

        if cx.resources.trigger_button.check_interrupt() {
            cx.resources.trigger_button.clear_interrupt_pending_bit();
            debug!("EXTI trigger pressed");
            trigger_pressed(cx.resources.last_ntc_temp, cx.resources.last_thermocouple_temp, cx.resources.weld_triggered);
        }
    }

    /// TIM8_UP Interrupt handles reading temperatures and updating the UI
    #[task(binds = TIM8_UP, resources = [
        ui_timer, 
        clocks, 
        display, 
        ntc_dma_buffer, 
        encoder,
        welder_ui,
        activity_led,
        thermocouple,
        last_ntc_temp,
        last_thermocouple_temp,
    ])]
    fn tim8_up(cx: tim8_up::Context) {
        static mut COUNT: u16 = 0;

        cx.resources.ui_timer.clear_update_interrupt_flag();

        ui_timer_elapsed(
            COUNT,
            cx.resources.activity_led,
            cx.resources.ntc_dma_buffer, 
            cx.resources.last_ntc_temp,
            cx.resources.thermocouple, 
            cx.resources.last_thermocouple_temp,
            cx.resources.welder_ui, 
            cx.resources.encoder, 
            cx.resources.display,
        );
    }

    /// TIM2 Interrupt
    /// This timer is connected to the ZC circuit (or countdown if dummy_zc feature is enabled)
    #[task(binds = TIM2, resources = [
        weld_triggered,
        welder_ui,
        ssr_timer,
        zc_in,
        clocks,
        status_led,
    ])]
    fn tim2(cx: tim2::Context) {
        // The current welding state
        static mut WELD_STATE: WeldState = WeldState::Idle;
        // Counter to progress through the current state
        static mut WELD_COUNTER: u16 = 0;
        // Local copies of config at trigger time
        static mut A_DELAY: u16 = 0;
        static mut B_ON: u16 = 0;
        static mut B_DELAY: u16 = 0;
        // The measured ZC period in microseconds. Measured just before weld is started and referred to until weld is finished
        static mut ZC_PERIOD_US: u16 = 0;

        // This is purely to divide the zc rate down to a level that is visible on the status led
        static mut COUNT: u16 = 0;

        // Clear the interrupt
        cx.resources.zc_in.clear_interrupt();

        *COUNT += 1;
        if *COUNT % 20 == 0 {
            cx.resources.status_led.on();
        } else {
            cx.resources.status_led.off();
        }

        zero_crossing_event(
            WELD_STATE,
            cx.resources.weld_triggered,
            WELD_COUNTER,
            cx.resources.welder_ui,
            A_DELAY,
            B_ON,
            B_DELAY,
            ZC_PERIOD_US,
            cx.resources.ssr_timer,
            cx.resources.zc_in,
            cx.resources.clocks,
        );
    }
};

/// This configures all peripherals. Mainly broken out to a function to allow the use of `?`
fn configure(mut device: DevicePeripherals, mut core: CorePeripherals) -> Result<init::LateResources, Error>{
    let mut rcc = device.RCC.constrain();
    let mut flash = device.FLASH.constrain();
    let mut gpioa = device.GPIOA.split(&mut rcc.apb2);
    let mut afio = device.AFIO.constrain(&mut rcc.apb2);
    let mut gpiob = device.GPIOB.split(&mut rcc.apb2);
    let dma1 = device.DMA1.split(&mut rcc.ahb);
    

    // PCB activity LED
    // It's configured here and set low (on) so that it's possible to tell
    // if the program has loaded without ITM for debugging. The `on`
    // can be moved down line by line to debug if the init function is ok
    // with OpenOCD connected but failing standalone. (Example of this
    // was that ITM logging wasn't checking ITM was enabled before querying
    // the STIM FIFO status.
    let mut usr_led = LedUsr::configure((gpioa.pa7, &mut gpioa.crl))?;
    usr_led.on();

    // After reset the clock is set to HSI and the TPIU clock scaler doesn't get reset 
    // (unless openocd relaunches or gdb is set to do this). Probably not necessary 
    // since we're immediatly configuring the clock and updating the itm again but it has
    // been useful in the past for debugging clock config code and doesn't do any harm
    itm_reset();

    // Configure the clock for full speed
    let clocks = Clocks::configure((rcc.cfgr, &mut flash.acr))?;

    itm_update_clocks(&clocks);

    info!("Configured max freq");

    let adc1 = Adc::adc1(device.ADC1, &mut rcc.apb2, clocks);
    let mut delay = Delay::new(core.SYST, clocks);

    let ht16k33 = {
        let res = Display::configure((
            &mut core.DWT,
            gpiob.pb10, //SCL
            gpiob.pb11, //SDA
            &mut gpiob.crh,
            &mut delay,
            device.I2C2, // I2C peripheral
            clocks,
            &mut rcc.apb1,
        ));
        // This is just for extra logging to quickly flag that it's the display that's failed (I2C is a bit flakey right now)
        if res.is_err() {
            error!("Configuring display failed");
        }
        res?
    };

    let thermocouple = Thermocouple::configure((
        KThermoNss::configure((gpiob.pb12, &mut gpiob.crh))?,
        KThermoSck::configure((gpiob.pb13, &mut gpiob.crh))?,
        KThermoMiso::configure((gpiob.pb14, &mut gpiob.crh))?,
        device.SPI2,
        clocks,
        &mut rcc.apb1,
    ))?;

    let ntc = Ntc::configure((gpiob.pb1, &mut gpiob.crl))?;
    //TODO: Configure::configure for these?
    // Configure the ADC and DMA for reading the NTC thermistor
    let ntc_dma = adc1.with_dma(
        ntc,
        dma1.1,
    );
    let ntc_buffer = singleton!(: [[u16; 8]; 2] = [[0; 8]; 2]).unwrap();
    let ntc_circ_buffer = ntc_dma.circ_read(ntc_buffer);

    let mut encoder = Encoder::configure((
        EncA::configure((gpiob.pb6, &mut gpiob.crl))?, 
        EncB::configure((gpiob.pb7, &mut gpiob.crl))?,
        device.TIM4, 
        clocks,
        &mut rcc.apb1,
        &mut afio.mapr,
    ))?;

    let enc_button = EncBtn::configure((
        gpiob.pb5,
        &mut gpiob.crl,
        &mut device.EXTI,
        &mut afio,
    ))?;

    let trigger_button = Trigger::configure((
        gpioa.pa8,
        &mut gpioa.crh,
        &mut device.EXTI,
        &mut afio,
    ))?;

    let led_status = LedStatus::configure((gpioa.pa2, &mut gpioa.crl))?;

    let _misc_en = MiscEn::configure((gpiob.pb15, &mut gpiob.crh))?;

    let zc_in = Zc::configure((
        ZcRising::configure((gpioa.pa0, &mut gpioa.crl))?,
        ZcFalling::configure((gpioa.pa1, &mut gpioa.crl))?,
        device.TIM2,
        clocks,
        &mut rcc.apb1,
        &mut afio.mapr,
        &mut device.DBGMCU,
    ))?;

    let ssr_timer = Ssr::configure((
        SsrEn::configure((gpioa.pa9, &mut gpioa.crh))?,
        LedSsrStatus::configure((gpioa.pa10, &mut gpioa.crh))?,
        device.TIM1,
        clocks,
        &mut rcc.apb2,
        &mut afio.mapr,
    ))?;
    
    let ui_timer = UiTimer::configure((device.TIM8, clocks, &mut rcc.apb2))?;

    let mut welder_ui = WelderUi::new();
    // Update the quad counter to match the current setting
    update_quad_from_setting_value(&mut encoder, *welder_ui.get_value_mut() as u16);

    info!("Init done");

    Ok(init::LateResources {
        ui_timer,
        encoder,
        zc_in,
        clocks,
        ntc_dma_buffer: ntc_circ_buffer,
        display: ht16k33,
        thermocouple,
        activity_led: usr_led,
        ssr_timer,
        enc_button,
        trigger_button,
        status_led: led_status,
        welder_ui,
    })
}

/// Called when the encoder button has been pressed, updates the UI
fn encoder_button_pressed(welder_ui: &mut WelderUi, encoder: &mut Encoder, display: &mut Display) {
    if let Err(e) = welder_ui.next_screen(display) {
        if HT16K33_MISSING_FATAL {
            panic!("Error moving to next UI screen: {:?}", e);
        } else {
            error!("Error moving to next UI screen: {:?}", e);
        }
    } else {
        if let Err(e) = display.write_display_buffer() {
            if HT16K33_MISSING_FATAL {
                panic!("HT16K33 error: {:?}", e);
            }
        }
    }
    update_quad_from_setting_value(encoder, *welder_ui.get_value_mut() as u16);
    info!("Encoder: {}", encoder.count());
}

/// Called when the trigger is pressed, checks the temperatures are safe and initiates a weld
fn trigger_pressed(ntc_temp: &f32, thermocouple_temp: &f32, weld_triggered: &mut bool) {
    let (ntc_ok, thermocouple_ok) = temps_ok(*ntc_temp, *thermocouple_temp);
    if ntc_ok && thermocouple_ok {
        info!("Trigger weld");
        *weld_triggered = true;
    } else {
        warn!("Temperature error: {} = {}, {} = {}", 
            *thermocouple_temp,
            ntc_ok,
            *thermocouple_temp,
            thermocouple_ok,
        );
    }
}

/// Updates the last_ntc_temp with a reading from the dma_buffer
fn read_ntc_temp(dma_buffer: &mut NtcDmaBufferHandle, last_ntc_temp: &mut f32) {
    //This is a hack to get around the overflow detection in the hal implementation
    //TODO: replace this with something better
    //      currently there are occasional erroneous readings due to the buffer being written while
    //      in use because of this hack
    unsafe { &(*DMA1::ptr()).ifcr.write(|w| w.chtif1().set_bit()); }
    let ntc_sample = dma_buffer
        .peek(|half, _| {
            half[0]
        }).unwrap_or(0);
    *last_ntc_temp = ntc_sample_to_degrees(ntc_sample);
}

/// Updates the last_thermocouple_temp with a value read from the max31855
#[cfg(feature = "thermocouple")]
fn read_thermocouple_temp(thermocouple: &mut Thermocouple, last_thermocouple_temp: &mut f32) {
    match thermocouple.0.read_thermocouple(&mut thermocouple.1, Unit::Celsius) {
        Ok(v) => *last_thermocouple_temp = v,
        Err(e) => warn!("Error reading thermocouple: {:?}", e),
    };
}

/// Called at 3hz to update the UI from the quad reading & due to elapsed time
fn tick_ui(welder_ui: &mut WelderUi, encoder: &Encoder, display: &mut Display) {
    let value = welder_ui.get_value_mut();
    let new_value = setting_value_from_quad(encoder) as u32;
    let changed = *value != new_value;

    let result = if changed {
        *value = new_value;
        welder_ui.reset_tick(display)
    } else {
        welder_ui.tick(Some(display))
    };

    if let Err(e) = result {
       if HT16K33_MISSING_FATAL {
            panic!("Error ticking UI: {:?}", e);
        } else {
            error!("Error ticking UI: {:?}", e);
        } 
    }

    if let Err(e) = display.write_display_buffer() {
        if HT16K33_MISSING_FATAL {
            panic!("HT16K33 error: {:?}", e);
        }
    }
}

/// Checks the temperatures are in acceptable range if range is specified
fn temps_ok(
    ntc_temp: f32, 
    #[cfg_attr(not(feature = "thermocouple"), allow(unused_variables))]
    thermocouple_temp: f32,
) -> (bool, bool) {
    let ntc_ok = if let Some((min, max)) = NTC_RANGE {
        ntc_temp >= min && ntc_temp <= max
    } else {
        true
    };
    let thermo_ok;

    #[cfg(feature = "thermocouple")]
    {
        thermo_ok = if let Some((min, max)) = THERMOCOUPLE_RANGE {
            thermocouple_temp >= min && thermocouple_temp <= max
        } else {
            true
        };
    }

    #[cfg(not(feature = "thermocouple"))]
    {
        thermo_ok = true;
    }

    (ntc_ok, thermo_ok)
}

/// Called at 3hz to read temperatures and update the UI
fn ui_timer_elapsed(
    count: &mut u16, 
    activity_led: &mut LedUsr,
    dma_buffer: &mut NtcDmaBufferHandle, 
    last_ntc_temp: &mut f32,
    #[cfg_attr(not(feature = "thermocouple"), allow(unused_variables))]
    thermocouple: &mut Thermocouple, 
    last_thermocouple_temp: &mut f32,
    welder_ui: &mut WelderUi, 
    encoder: &Encoder, 
    display: &mut Display,
) {
    // Turn on the led to show activity
    activity_led.on();

    // Update the NTC temp
    read_ntc_temp(dma_buffer, last_ntc_temp);        

    // Update the thermocouple temp
    #[cfg(feature = "thermocouple")]
    read_thermocouple_temp(thermocouple, last_thermocouple_temp);

    // Tick the UI
    tick_ui(welder_ui, encoder, display);

    if *count % 20 == 0 {
        #[cfg_attr(not(feature = "thermocouple"), allow(unused_variables))]
        let (ntc_ok, thermocouple_ok) = temps_ok(*last_ntc_temp, *last_thermocouple_temp);
        info!("ntc_temp: {} (ok? {})",
            *last_ntc_temp, 
            ntc_ok, 
        );

        #[cfg(feature = "thermocouple")]
        info!("thermocouple_temperature: {} (ok? {})",
            *last_thermocouple_temp, 
            thermocouple_ok,
        );
    }

    // Turn the led off again
    activity_led.off();
    *count += 1;
}

/// Called when a zero crossing even occurs, typically at 100hz or 120hz depending on mains frequency
/// Performs weld specified by weld_settings if weld_triggered is set
fn zero_crossing_event(
    weld_state: &mut WeldState,
    weld_triggered: &mut bool,
    weld_counter: &mut u16,
    welder_ui: &WelderUi,
    a_delay: &mut u16,
    b_on: &mut u16,
    b_delay: &mut u16,
    zc_period_us: &mut u16,
    ssr_timer: &mut Ssr,
    #[cfg_attr(feature = "dummy_zc", allow(unused_variables))]
    zc_in: &Zc,
    #[cfg_attr(feature = "dummy_zc", allow(unused_variables))]
    clocks: &Clocks,
) {
    // Converts microseconds to zero crossing count
    let pulse_us_to_zc = |us: u32, zc_period_us: u16| -> u16 {
        (us as u16 + (zc_period_us / 2)) / zc_period_us
    };

    // Converts number of zero crossings to a pulse period microseconds
    // Adds half a period to make sure we catch the start of the final zero crossing
    let zc_to_pulse_us = |zc: u16, zc_period_us: u16| -> u16 {
        zc * zc_period_us + zc_period_us / 2
    };

    if *weld_state == WeldState::Idle {
        if *weld_triggered {
            let freq;
            #[cfg(feature = "dummy_zc")]
            {
                freq = DUMMY_FREQ.0 as u16;
            }
            #[cfg(not(feature = "dummy_zc"))]
            {
                freq = zc_in
                    .read_frequency(ReadMode::Instant, clocks)
                    .unwrap_or(0.hz()).0 as u16;
            }

            let (_, actual_mains_freq) = ACCEPTABLE_ZC_FREQ_RANGES
                .iter()
                .find(|(range, _)| range.contains(&freq))
                //TODO: Do something nicer than panic once UI is a bit more polished
                .unwrap_or_else(|| panic!("Actual frequency ({}) is outside of acceptable ranges", freq));

            *zc_period_us = 1000 / *actual_mains_freq;

            let snapshot = welder_ui.settings_snapshot();

            *weld_state = WeldState::AWeld;
            *weld_counter = pulse_us_to_zc(snapshot.a_on, *zc_period_us);
            *a_delay = pulse_us_to_zc(snapshot.a_delay, *zc_period_us);
            *b_on = pulse_us_to_zc(snapshot.b_on, *zc_period_us);
            *b_delay = pulse_us_to_zc(snapshot.b_delay, *zc_period_us);
            

            debug!("WELDING. Config ([set] => [actual]):");
            debug!("  a_on: {} => {}",
                snapshot.a_on,
                zc_to_pulse_us(*weld_counter, *zc_period_us),
            );
            debug!("  a_delay: {} => {}",
                snapshot.a_delay,
                zc_to_pulse_us(*a_delay, *zc_period_us),                
            );
            debug!("  b_on: {} => {}", 
                snapshot.b_on,
                zc_to_pulse_us(*b_on, *zc_period_us),                
            );
            debug!("  b_delay: {} => {}",
                snapshot.b_delay,
                zc_to_pulse_us(*b_delay, *zc_period_us),               
            );
            debug!("  mains freq: {}", actual_mains_freq);

            ssr_timer.pulse(zc_to_pulse_us(*weld_counter, *zc_period_us) as u32);
        }
    } else {
        let done = if *weld_counter > 0 {
            *weld_counter -= 1;
            false
        } else {
            true 
        };

        if done {
            match *weld_state {
                WeldState::Idle => unreachable!(),
                WeldState::AWeld => {
                    *weld_counter = *a_delay;
                    *weld_state = WeldState::ADelay;
                },
                WeldState::ADelay => {
                    *weld_counter = *b_on;
                    *weld_state = WeldState::BWeld;
                    ssr_timer.pulse(
                        zc_to_pulse_us(
                            *weld_counter, 
                            *zc_period_us) as u32
                    );
                },
                WeldState::BWeld => {
                    *weld_counter = *b_delay;
                    *weld_state = WeldState::BDelay;
                },
                WeldState::BDelay => {
                    *weld_state = WeldState::Idle;
                    *weld_triggered = false;
                },
            }
        }
    }
}
    

/// Disables the timer, updates the count register, re-enables the timer.
/// Doesn't actually use the parameter because this functionality isn't available on hal interface
fn update_quad_count(_quad: &mut Encoder, count: u16) {
    unsafe {
        let tim = &(*QuadTim::ptr());
        tim.cr1.modify(|_, w| w.cen().clear_bit());
        tim.cnt.write(|w| w.cnt().bits(count));
        tim.cr1.modify(|_, w| w.cen().set_bit());
    }
}

/// Returns the quad count scaled to the settings range
fn setting_value_from_quad(quad: &Encoder) -> u16 {
    quad.count() * QUAD_SCALE % 999
}

/// Reverses the setting scaling and updates the quad count
fn update_quad_from_setting_value(quad: &mut Encoder, value: u16) {
    update_quad_count(quad, value / QUAD_SCALE);
}

/// Steinhart conversion from NTC sample to degreec celsius
fn ntc_sample_to_degrees(sample: u16) -> f32 {
    let adc_sample = sample as f32;
    let adc_v = VCC_F * adc_sample / ADC_MAX_F;
    let ntc_r = adc_v * NTC_FIXED_RES / (VCC_F - adc_v);

    let mut steinhart = ntc_r;

    steinhart /= NTC_NOMINAL_RES;
    steinhart = steinhart.ln();
    steinhart /= NTC_B_COEFF;
    steinhart += 1. / (NTC_NOMINAL_TEMP + CELCIUS_KELVIN_OFFSET);
    if steinhart == 0. {
        panic!("Div by 0");
    }
    steinhart = 1. / steinhart;
    steinhart -= CELCIUS_KELVIN_OFFSET;

    steinhart
}

#[panic_handler]
fn panic(
    #[cfg_attr(not(feature = "itm"), allow(unused_variables))]
    info: &PanicInfo
) -> ! {
    interrupt::disable();

    #[cfg(feature = "itm")]
    {
        let itm = unsafe { &mut *ITM::ptr() };
        let stim = &mut itm.stim[0];

        iprintln!(stim, "{}", info);
    }

    loop {
        // add some side effect to prevent this from turning into a UDF instruction
        // see rust-lang/rust#28728 for details
        atomic::compiler_fence(Ordering::SeqCst)
    }
}

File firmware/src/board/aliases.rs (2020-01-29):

use stm32f1xx_hal::{
    gpio::{
        PushPull,
        Alternate,
        Input,
        Output,
        Floating,
        OpenDrain,
        Analog,
        gpioa::*,
        gpiob::*,
    },    
    timer::{
        Tim4NoRemap,
        CountDownTimer,
    },
    spi::{
        Spi,
        Spi2NoRemap,
        NoMosi,
    },
    i2c::BlockingI2c,
    pac::{
        I2C2,
        SPI2,
        TIM2,
        TIM4,
        TIM8,
        TIM1,
    },
    qei::Qei,
    pwm::{
        Pwm,
        C2,
        C3,
    },
};

#[cfg(not(feature = "dummy_zc"))]
use stm32f1xx_hal::{ 
    pwm_input::PwmInput,
    timer::Tim2NoRemap,
};
use ht16k33::HT16K33;

/// Zero crossing timer reads pwm input from the zero crossing detection circuit (or a dummy count down timer if dummy_zc feature is enabled)
pub type ZcTim = TIM2;
/// Quadrature encoder timer reads the quad input from the rotary encoder
pub type QuadTim = TIM4;
/// The UI timer provides a periodic interrupt to update the display, read temperature and periodically log useful info
pub type UiTim = TIM8;
/// The SSR timer drives the SsrEn pin to enable the welder. A timer is used so the control software crashing should never result in the SSR being left enabled
pub type SsrTim = TIM1;

/// The complete handle for the UI timer
pub type UiTimer = CountDownTimer<UiTim>;

/// Debug LED on PCB near MCU
/// TIM3_CH2
pub type LedUsr         = PA7<Output<PushPull>>;

/// Status LED to indicate ready, error, etc.
/// TIM5_CH3 (or TIM2_CH3)
pub type LedStatus      = PA2<Output<PushPull>>;

/// Status LED to indicate SSR status. Typically same state as SSR_EN
/// TIM1_CH3
pub type LedSsrStatus   = PA10<Alternate<PushPull>>;

/// Output that triggers SSR to allow current flow. Active high
/// TIM1_CH2
pub type SsrEn          = PA9<Alternate<PushPull>>;

/// Complete handle for the SSR output
pub type Ssr = (Pwm<SsrTim, C2>, Pwm<SsrTim, C3>);

/// Misc output (fans etc)
pub type MiscEn         = PB15<Output<PushPull>>;

/// Rotary encoder push button input. Active low
/// EXTI5
pub type EncBtn         = PB5<Input<Floating>>;

/// Rotary encoder quadrature input A
/// TIM4_CH1
pub type EncA           = PB6<Input<Floating>>;

/// Rotary encoder quadrature input B
/// TIM4_CH2
pub type EncB           = PB7<Input<Floating>>;

/// Complete handle for the encoder
pub type Encoder        = Qei<QuadTim, Tim4NoRemap, (EncA, EncB)>;

/// NTC thermister input. Half way point of resistor divider VCC-10k-\[NTC\]-GND
/// ADC1_CH9 (or ADC2_CH9)
pub type Ntc            = PB1<Analog>;

/// Input from zero crossing detection circuit. Active low
/// TIM2_CH1
pub type ZcRising       = PA0<Input<Floating>>;
/// Input from zero crossing detection circuit. Active low
/// TIM2_CH2
pub type ZcFalling      = PA1<Input<Floating>>;

#[cfg(not(feature = "dummy_zc"))] 
/// Complete handle for the Zc timer
pub type Zc = PwmInput<ZcTim, Tim2NoRemap, (ZcRising, ZcFalling)>;

#[cfg(feature = "dummy_zc")] 
/// Complete handle for the Zc timer
pub type Zc = CountDownTimer<ZcTim>;

/// User input trigger. Active low
/// EXTI8
pub type Trigger        = PA8<Input<Floating>>;

/// I2C clock for quad 14(?) segment display
/// I2C2
pub type DispScl        = PB10<Alternate<OpenDrain>>;

/// I2C data for quad 14(?) segment display
/// I2C2
pub type DispSda        = PB11<Alternate<OpenDrain>>;

/// The complete handle for the HT16K33 Display
pub type Display        = HT16K33<BlockingI2c<I2C2, (DispScl, DispSda)>>;

/// USB D-
pub type UsbDm<T>       = PA11<T>;

/// USB D+
pub type UsbDp<T>       = PA12<T>;

/// MAX31855K thermocouple converter - slave select, active low
/// Spi2
pub type KThermoNss     = PB12<Output<PushPull>>;

/// MAX31855K thermocouple converter - serial-clock
/// Spi2
pub type KThermoSck     = PB13<Alternate<PushPull>>;

/// MAX31855K thermocouple converter - serial data out
/// Spi2
pub type KThermoMiso    = PB14<Input<Floating>>;

/// Complete handle for the MAX31855 thermocouple
pub type Thermocouple = (Spi<SPI2, Spi2NoRemap, (KThermoSck, KThermoMiso, NoMosi)>, KThermoNss);

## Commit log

2019-11-11 Added some images of the boards
2019-11-11 Added v0.2 hardware files
    [zero_crossing_detector.kicad_pcb, zero_crossing_detector.sch]
2019-11-11 Documentation for sending PCB to JLCPCB and setting up the dev environment
2019-11-11 Added open hardware logo to PCB. Fixed some doc typos
    [zero_crossing_detector.kicad_pcb]
2019-11-13 Changed to 5v AC-DC module. Added transistor to drive SSR output. Updated LDO
    [zero_crossing_detector.kicad_pcb, zero_crossing_detector.sch]
2019-11-14 Added some extra silkscreen labels to IO. Fixed image links in project log
    [zero_crossing_detector.kicad_pcb]
2019-11-14 Updated parts list to match latest pcb changes
2019-11-14 Mostly functional 'UI' - pressing enc button cycles through, rotating changes the current setting. Encoder is a bit too sensitive for a single count to be a single step; this can be tweaked in code l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
2019-11-15 Added tiny 1x1mm RGB LED to pcb
    [zero_crossing_detector.kicad_pcb, zero_crossing_detector.sch]
2019-11-16 Switched USB ESD diode for STM recommened one. Added GND plane around USB traces on top layer
    [zero_crossing_detector.kicad_pcb, zero_crossing_detector.sch]
2019-11-16 Tweaked solder mask expansion
    [zero_crossing_detector.kicad_pcb, zero_crossing_detector.sch]
2019-11-21 Moved kicad custom footprints & components to a git submodule
2019-12-18 Rotated RGB led
    [zero_crossing_detector.kicad_pcb]
2020-01-09 Reading from MAX31855 and some clean up in prep for new board
2020-01-14 Fixed casing of resources to match rtfm 5 style
    [spot_welder.rs]
2020-01-25 Added hw debouncing to trigger. Added SCL pull-up. Made both I2C pull-ups 2.2k and optional
    [zero_crossing_detector.kicad_pcb, zero_crossing_detector.sch]
2020-01-26 Split board.rs up into multiple files. Documentation. Moved most hardware config from bin to lib
2020-01-27 Switched to crates.io version of i2c_hung_fix and back to the github version of stm32f1xx-hal
2020-01-28 Shuffled board around to put AC/DC right on the edge so hopefully it will fit alongside an SSR mounted in the lid of the box
    [zero_crossing_detector.kicad_pcb, zero_crossing_detector.sch]
2020-01-29 Removed RGB led
    [zero_crossing_detector.kicad_pcb, zero_crossing_detector.sch]
2020-01-29 Switched to serialitm instead of hacky d2xx version. Updated docs
2021-11-08 Update README.md
    https://forum.kicad.info/t/warning-avoid-all-links-to-kicad-pcb-org-use-kicad-org/31521
